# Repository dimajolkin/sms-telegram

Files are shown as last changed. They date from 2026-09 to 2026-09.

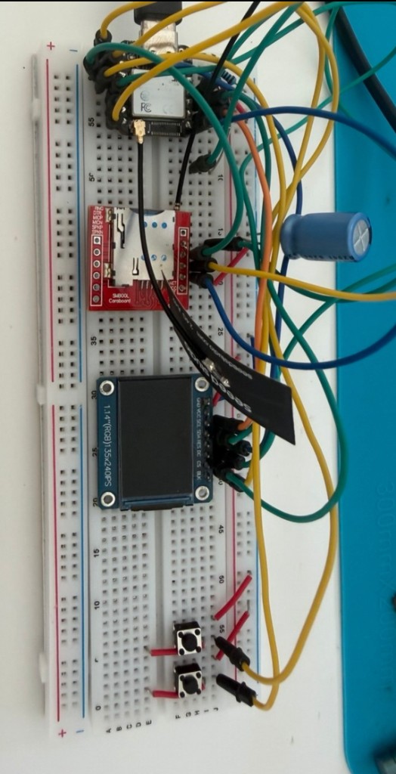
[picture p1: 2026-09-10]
docs/hardware/breadboard-prototype.jpg

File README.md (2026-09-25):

# SMS ↔ Telegram gateway (PlatformIO / Arduino)

Firmware for **Seeed XIAO ESP32-S3** that bridges a **SIM800L** cellular modem and **Telegram Bot API** over Wi‑Fi, with a Nokia-style **ST7789** status screen.

Uses **native ESP Wi‑Fi + mbedTLS** and **two FreeRTOS cores**. The device is a **gateway**: accept SMS / events and forward to Telegram — not a message store.

```text
  Phone / SMS ──► SIM800L ──UART──► XIAO ESP32-S3 ──Wi‑Fi TLS──► Telegram
                      ▲                    │
                      │                    └── ST7789 status UI
                 USSD / CLIP
```

| Core | Tasks |
|---|---|
| **0** (PRO) | Wi‑Fi stack, NTP, Telegram HTTPS / long-poll, outbound queue |
| **1** (APP) | SIM800L UART, SMS/CLIP poll, weekly balance check, ST7789 + buttons |

## Features

| Feature | Behavior |
|---|---|
| Incoming SMS | Queued → Telegram (UCS-2 decoded), then **deleted from SIM** |
| Missed calls | `AT+CLIP` → Telegram after ring silence |
| Outgoing SMS | `/sms +7900… text` |
| USSD / balance | `/balance` (`*100#`), `/ussd *code#` |
| Weekly balance | Every **7 days** (`*100#`); Telegram warning if balance **&lt; 100** |
| Missed list | `/missed` (modem MC/RC phonebook) |
| Status UI | Signal, Wi‑Fi, clock, **QUEUE** (pending TG sends), CALLS, **IP**, softkeys |
| Inbox | Browse SIM leftovers; **Next** = next / exit after last, **Back** = status |
| Buttons | D0 = Next / Inbox, D1 = OK / Refresh / Back (to GND) |

## Hardware

- [Seeed XIAO ESP32-S3](https://wiki.seeedstudio.com/xiao_esp32s3_getting_started/)
- SIM800L (or compatible) + SIM with SMS
- ST7789V 1.14″ IPS (135×240), rotation 180° in firmware
- Two momentary buttons to GND
- Bulk capacitor on modem VCC

Enclosure / STL / Fusion: [`hardware/enclosure/`](hardware/enclosure/). Photos: [`docs/hardware/`](docs/hardware/).

### Pinout (XIAO)

| Function | XIAO | GPIO |
|---|---|---|
| Modem RX ← MCU TX | **D6** | 43 |
| Modem TX → MCU RX | **D7** | 44 |
| Modem RST (idle HIGH) | **D2** | 3 |
| TFT SCL | D8 | 7 |
| TFT SDA (MOSI) | D10 | 9 |
| TFT CS | D9 | 8 |
| TFT DC | D4 | 5 |
| TFT RES | D5 | 6 |
| TFT BLK | D3 | 4 |
| Button Next | D0 → GND | 1 |
| Button OK | D1 → GND | 2 |

## Requirements

- [PlatformIO](https://platformio.org/) CLI (`pio`)
- Wi‑Fi credentials + Telegram bot token ([@BotFather](https://t.me/BotFather))

## Quick start

```bash
cp firmware/secrets.ini.example firmware/secrets.ini
# edit WIFI_SSID, WIFI_PASSWORD, TELEGRAM_BOT_TOKEN, TELEGRAM_CHAT_ID

make flash          # or: cd firmware && pio run -t upload
make monitor
```

Open the bot, send `/start` or `/help`. Incoming SMS and missed calls appear automatically. **QUEUE** on the screen is the Telegram outbound backlog (decrements after each successful send).

### Example commands

```text
/help
/balance
/missed
/sms +79001112233 hello
/ussd *100#
```

## Project layout

```text
firmware/            PlatformIO project (Arduino + FreeRTOS)
  platformio.ini
  secrets.ini.example
  include/           pins, config, events, headers
  src/               main, modem, telegram, ui, display, …
hardware/enclosure/  case STL / Fusion
```

## Notes

- Boot order: display → Wi‑Fi/NTP → UART/modem → Telegram → pinned tasks.
- Screen sleeps after 30 s idle; wake on button or SMS / missed call.
- Balance check timestamp is stored in NVS (`sms-gw` / `bal_chk`); first run ~2 min after boot, then every 7 days.

## License

Use and modify as you like for personal / educational projects.

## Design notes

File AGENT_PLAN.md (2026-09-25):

# AGENT_PLAN — SMS → Telegram (PlatformIO)

Notion: **SMS → Telegram** (Hobby).

## Архитектура

Seeed XIAO ESP32S3 + SIM800L + ST7789V 1.14.
PlatformIO Arduino + FreeRTOS: Core0 WiFi/Telegram, Core1 modem/UI.

## Команды бота

- `/start`, `/sms`, `/ussd`, `/balance`, `/missed`, `/help`

## UI (кнопки)

- Next (D0): Status→Inbox / следующий SMS
- OK (D1): refresh / Back на Status

## Очередь

1. `make flash` при подключённом USB
2. Проверить Status (QUEUE, IP) + Inbox Back
3. Реальный SMS / USSD

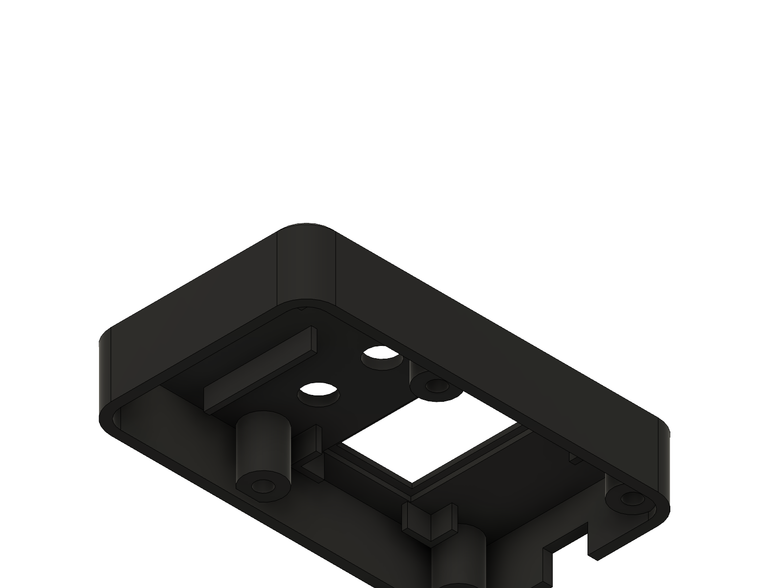
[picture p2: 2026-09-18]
docs/hardware/enclosure-shell-inside.png

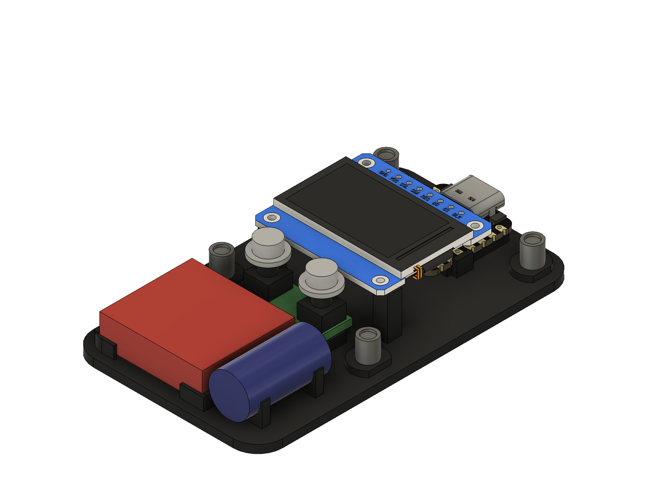
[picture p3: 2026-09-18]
docs/hardware/enclosure-packing.png

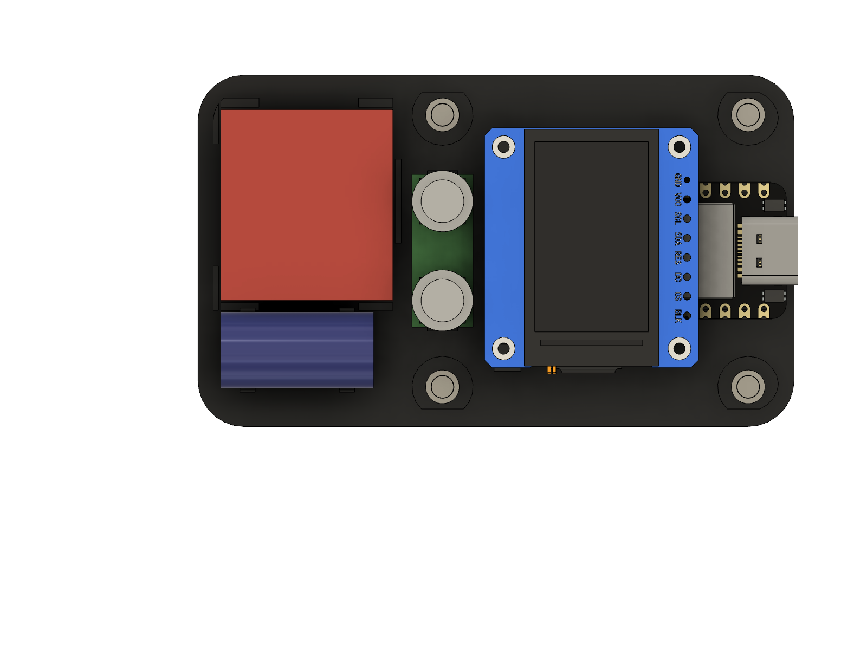
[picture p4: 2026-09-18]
docs/hardware/enclosure-packing-top.png

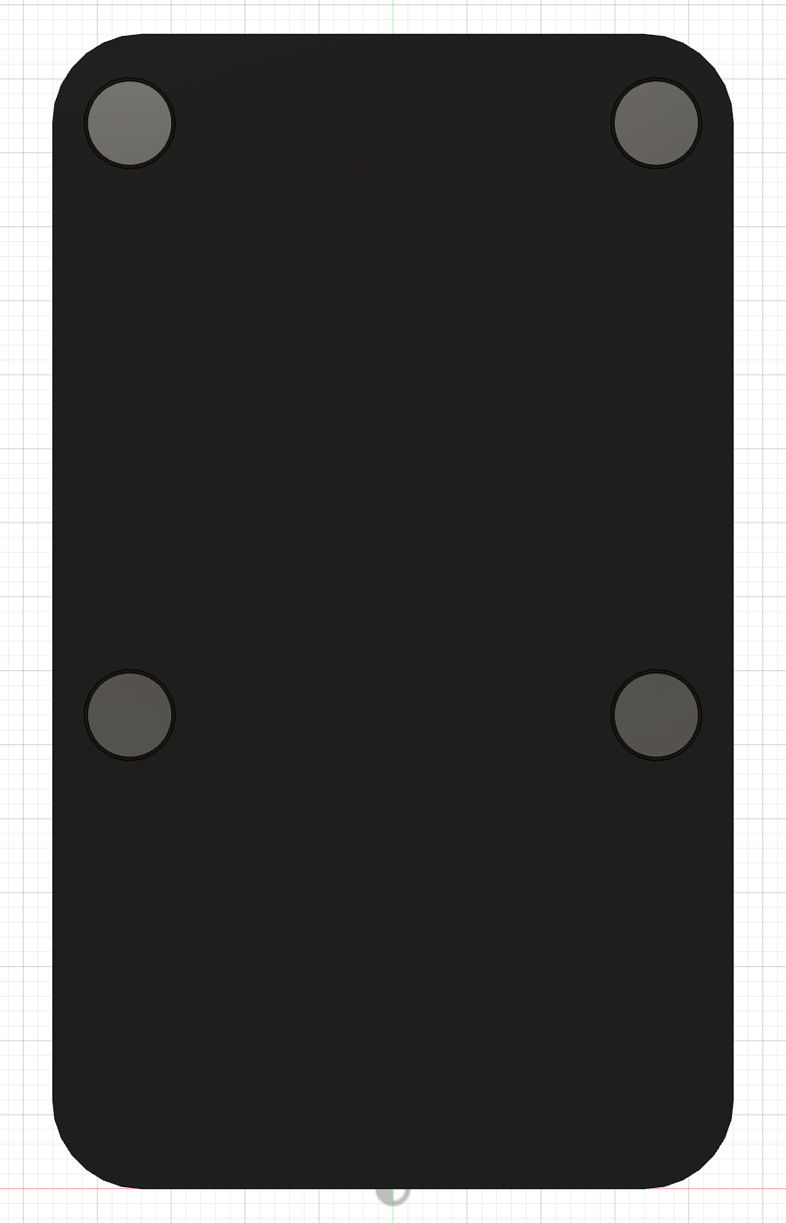
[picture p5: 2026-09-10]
docs/hardware/enclosure-bottom.png

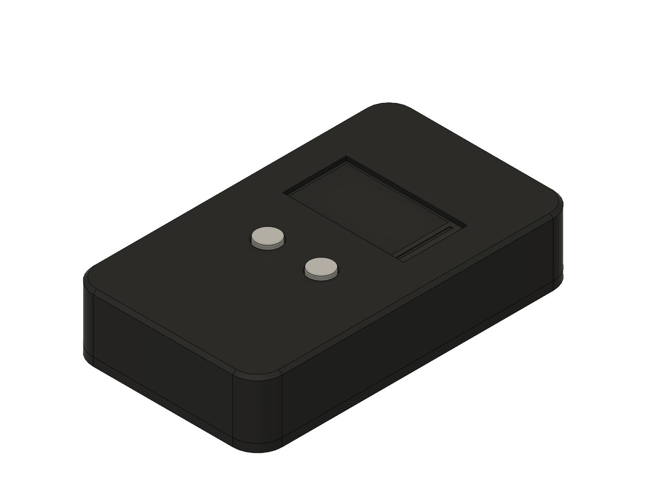
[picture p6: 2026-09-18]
docs/hardware/enclosure-iso.png

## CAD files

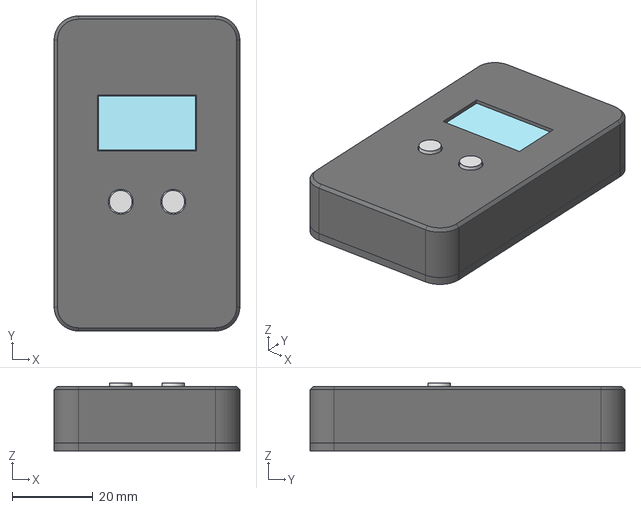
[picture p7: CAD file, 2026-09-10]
hardware/enclosure/sms-telegram-enclosure.step
46.0 x 78.0 x 16.8 mm

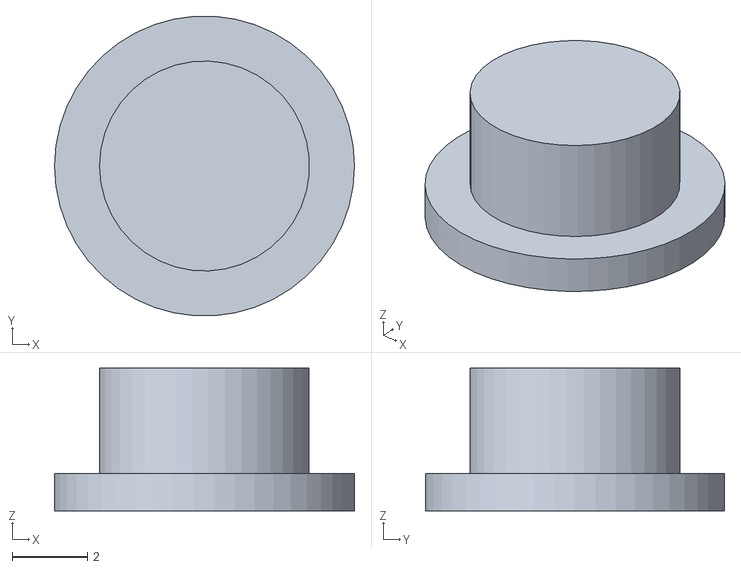
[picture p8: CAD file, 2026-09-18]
hardware/enclosure/stl/button-cap-x2.stl
8.00 x 7.98 x 3.80

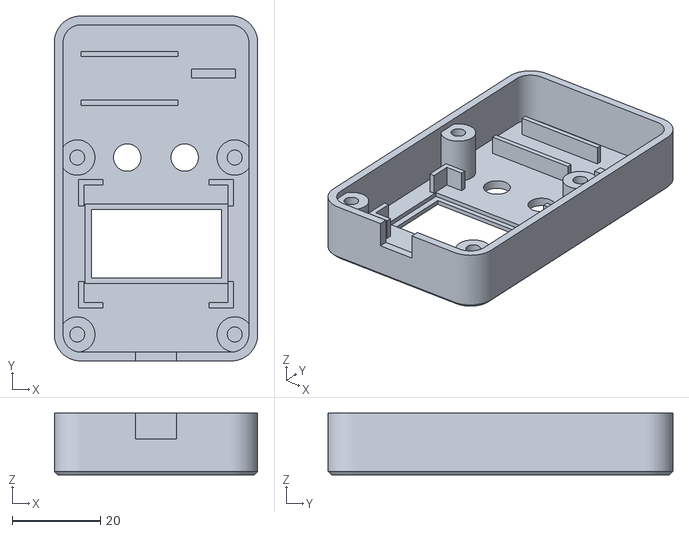
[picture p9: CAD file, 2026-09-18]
hardware/enclosure/stl/enclosure-shell.stl
46.0 x 78.0 x 14.0

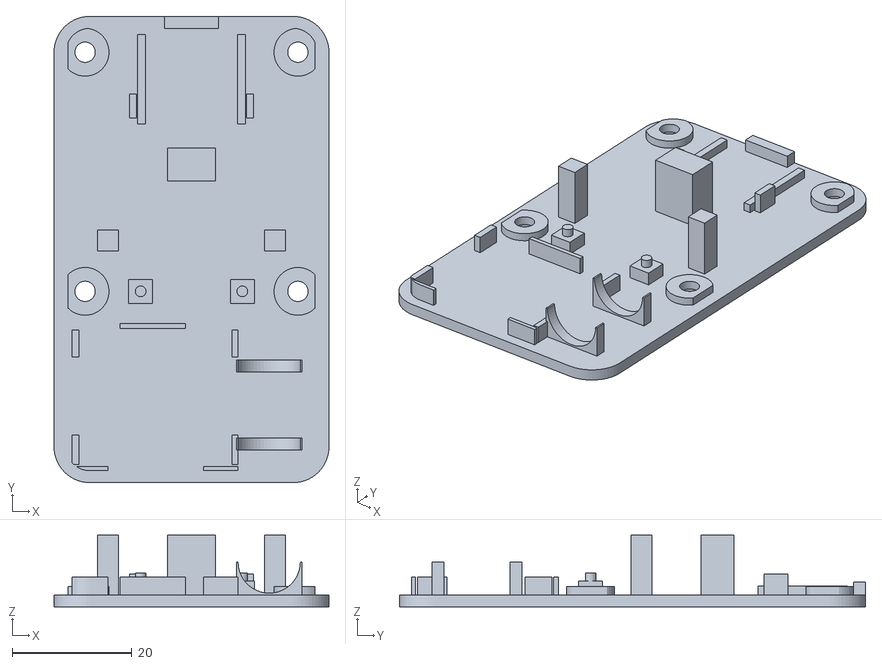
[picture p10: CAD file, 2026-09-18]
hardware/enclosure/stl/enclosure-cover.stl
46.0 x 78.0 x 12.0

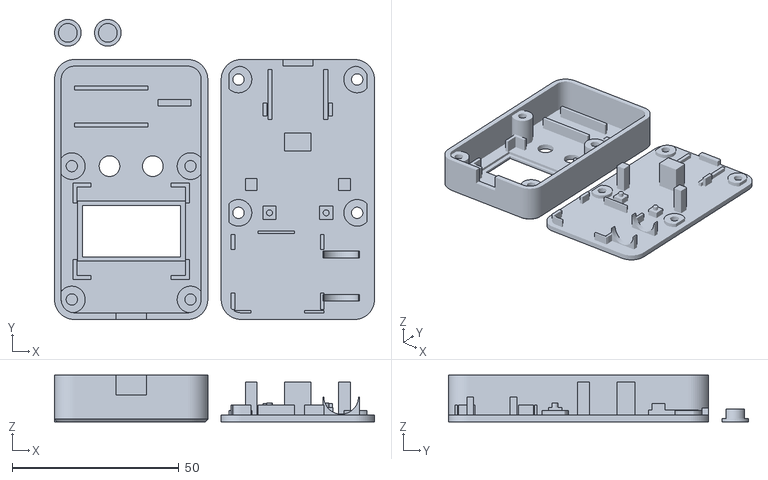
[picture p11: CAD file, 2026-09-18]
hardware/enclosure/stl/plate-100x160.stl
96.0 x 90.0 x 14.0

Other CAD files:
hardware/enclosure/sms-telegram-enclosure.f3d

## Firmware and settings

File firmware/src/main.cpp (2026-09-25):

#include <Arduino.h>
#include <HardwareSerial.h>
#include <Preferences.h>
#include <freertos/FreeRTOS.h>
#include <freertos/queue.h>
#include <freertos/semphr.h>
#include <freertos/task.h>
#include <ctype.h>
#include <stdlib.h>
#include <time.h>

#include "buttons.h"
#include "commands.h"
#include "config.h"
#include "display.h"
#include "events.h"
#include "modem.h"
#include "pins.h"
#include "status.h"
#include "telegram.h"
#include "ui.h"
#include "wifi_ntp.h"

static HardwareSerial ModemUART(1);
static SemaphoreHandle_t g_modem_mu;
static QueueHandle_t g_to_tg;
static QueueHandle_t g_to_modem;
static SharedStatus g_status;
static Modem g_modem;
static Telegram g_tg;
static Display g_disp;
static Buttons g_btns;
static UI g_ui;

static char g_chat_id[32];
static SemaphoreHandle_t g_chat_mu;

static void chat_set(const char *id) {
  if (xSemaphoreTake(g_chat_mu, pdMS_TO_TICKS(200)) != pdTRUE) return;
  strncpy(g_chat_id, id ? id : "", sizeof(g_chat_id) - 1);
  g_chat_id[sizeof(g_chat_id) - 1] = 0;
  xSemaphoreGive(g_chat_mu);
}

static void chat_get(char *out, size_t out_len) {
  out[0] = 0;
  if (xSemaphoreTake(g_chat_mu, pdMS_TO_TICKS(100)) != pdTRUE) return;
  strncpy(out, g_chat_id, out_len - 1);
  out[out_len - 1] = 0;
  xSemaphoreGive(g_chat_mu);
}

static void enqueue_tg(const TgEvent &ev) {
  if (xQueueSend(g_to_tg, &ev, pdMS_TO_TICKS(500)) == pdTRUE)
    status_tg_queue_add(&g_status, 1);
}

static void enqueue_text(const char *text) {
  TgEvent ev{};
  ev.type = TG_EVT_TEXT;
  ev.sms_index = -1;
  strncpy(ev.text, text, sizeof(ev.text) - 1);
  enqueue_tg(ev);
}

static bool tg_send_and_ack(const char *dest, const char *text) {
  bool ok = g_tg.send(dest, text);
  if (ok) status_tg_queue_add(&g_status, -1);
  return ok;
}

// Первое число вида 123 / 123.45 / 123,45 из ответа USSD.
static bool parseBalanceAmount(const char *text, float *out) {
  if (!text || !out) return false;
  for (const char *p = text; *p; p++) {
    if (!isdigit((unsigned char)*p)) continue;
    char buf[32];
    size_t n = 0;
    bool seen_sep = false;
    while (*p && n + 1 < sizeof(buf)) {
      if (isdigit((unsigned char)*p)) {
        buf[n++] = *p++;
      } else if ((*p == '.' || *p == ',') && !seen_sep) {
        seen_sep = true;
        buf[n++] = '.';
        p++;
      } else {
        break;
      }
    }
    buf[n] = 0;
    if (n == 0) continue;
    char *end = nullptr;
    float v = strtof(buf, &end);
    if (end != buf) {
      *out = v;
      return true;
    }
  }
  return false;
}

static void maybeCheckBalance() {
  time_t now = time(nullptr);
  if (now < 1700000000) return;  // NTP ещё нет

  static Preferences prefs;
  static bool prefs_open = false;
  if (!prefs_open) {
    prefs.begin("sms-gw", false);
    prefs_open = true;
  }

  time_t last = (time_t)prefs.getULong("bal_chk", 0);
  if (last == 0) {
    if (millis() < BALANCE_FIRST_CHECK_AFTER_MS) return;
  } else if (now - last < BALANCE_CHECK_INTERVAL_SEC) {
    return;
  }

  Serial.println("balance: weekly check *100#…");
  char resp[400];
  if (!g_modem.ussd("*100#", resp, sizeof(resp)) || !resp[0]) {
    Serial.println("balance: ussd fail, retry in 1d");
    // не ждать ещё 7 дней при ошибке
    prefs.putULong("bal_chk",
                   (uint32_t)(now - BALANCE_CHECK_INTERVAL_SEC + 86400));
    return;
  }
  prefs.putULong("bal_chk", (uint32_t)now);

  float bal = 0;
  if (!parseBalanceAmount(resp, &bal)) {
    Serial.printf("balance: parse fail [%s]\n", resp);
    return;
  }
  Serial.printf("balance: %.2f\n", bal);
  if (bal < BALANCE_WARN_BELOW) {
    char msg[220];
    snprintf(msg, sizeof(msg),
             "Низкий баланс: %.2f ₽ (порог %.0f).\n%s", bal,
             BALANCE_WARN_BELOW, resp);
    enqueue_text(msg);
  }
}

static void handle_update(const TgUpdate &u) {
  if (!u.has_message || u.text.length() == 0) return;
  String text = u.text;
  text.trim();
  char from[32];
  snprintf(from, sizeof(from), "%lld", (long long)u.chat_id);

  if (text.startsWith("/start")) {
    chat_set(from);
    enqueue_text("Подписка активна.\n/help");
    return;
  }

  char bound[32];
  chat_get(bound, sizeof(bound));
  if (bound[0] && strcmp(bound, from) != 0) {
    TgEvent ev{};
    ev.type = TG_EVT_TEXT;
    ev.sms_index = -1;
    strncpy(ev.from, from, sizeof(ev.from) - 1);
    strncpy(ev.text, "Этот бот привязан к другому chat id.", sizeof(ev.text) - 1);
    // send to requester: stash chat in from, special — use send with from
    // simpler: send directly
    g_tg.send(from, "Этот бот привязан к другому chat id.");
    return;
  }
  if (!bound[0]) chat_set(from);

  if (cmdMatch(text, "help")) {
    enqueue_text(helpText().c_str());
  } else if (cmdMatch(text, "balance")) {
    ModemCmd cmd{};
    cmd.type = MODEM_CMD_USSD;
    strncpy(cmd.arg1, "*100#", sizeof(cmd.arg1) - 1);
    xQueueSend(g_to_modem, &cmd, pdMS_TO_TICKS(500));
    enqueue_text("USSD *100#…");
  } else if (cmdMatch(text, "missed")) {
    ModemCmd cmd{};
    cmd.type = MODEM_CMD_LIST_MISSED;
    xQueueSend(g_to_modem, &cmd, pdMS_TO_TICKS(500));
    enqueue_text("Читаю пропущенные…");
  } else if (text.startsWith("/sms ")) {
    String num, body;
    if (!parseSMSCmd(text, &num, &body)) {
      enqueue_text("Формат: /sms +79001112233 текст");
      return;
    }
    ModemCmd cmd{};
    cmd.type = MODEM_CMD_SEND_SMS;
    strncpy(cmd.arg1, num.c_str(), sizeof(cmd.arg1) - 1);
    strncpy(cmd.arg2, body.c_str(), sizeof(cmd.arg2) - 1);
    xQueueSend(g_to_modem, &cmd, pdMS_TO_TICKS(500));
    enqueue_text("Отправляю SMS…");
  } else if (text.startsWith("/ussd ")) {
    String code = text.substring(6);
    code.trim();
    if (code.length() == 0) {
      enqueue_text("Формат: /ussd *100#");
      return;
    }
    ModemCmd cmd{};
    cmd.type = MODEM_CMD_USSD;
    strncpy(cmd.arg1, code.c_str(), sizeof(cmd.arg1) - 1);
    xQueueSend(g_to_modem, &cmd, pdMS_TO_TICKS(500));
    char msg[80];
    snprintf(msg, sizeof(msg), "USSD %s…", code.c_str());
    enqueue_text(msg);
  } else {
    enqueue_text("Не знаю команду. /help");
  }
}

static void telegram_task(void *arg) {
  (void)arg;
  Serial.printf("telegram_task on core %d\n", xPortGetCoreID());
  int64_t offset = 0;
  int fails = 0;
  uint32_t last_poll = 0;

  // drain backlog once
  {
    TgUpdate ups[3];
    int n = 0;
    int64_t next = 0;
    if (g_tg.getUpdates(0, 0, ups, &n, 3, &next)) {
      offset = next;
      for (int i = 0; i < n; i++) handle_update(ups[i]);
    }
  }

  char chat[32];
  chat_get(chat, sizeof(chat));
  if (chat[0]) g_tg.send(chat, "ESP online. /help");

  for (;;) {
    TgEvent ev;
    while (xQueueReceive(g_to_tg, &ev, 0) == pdTRUE) {
      chat_get(chat, sizeof(chat));
      if (!chat[0] && ev.type != TG_EVT_TEXT) {
        // нет подписчика — вернуть в очередь, не терять
        xQueueSend(g_to_tg, &ev, 0);
        break;
      }
      const char *dest = chat;
      bool ok = false;
      if (ev.type == TG_EVT_SMS) {
        char msg[520];
        snprintf(msg, sizeof(msg), "SMS from %s\n\n%s", ev.from, ev.text);
        ok = tg_send_and_ack(dest, msg);
        if (ok && ev.sms_index >= 0) {
          g_modem.deleteSMS(ev.sms_index);  // шлюз: не храним на SIM
        } else if (!ok) {
          xQueueSend(g_to_tg, &ev, 0);
          break;
        }
      } else if (ev.type == TG_EVT_MISSED) {
        char msg[96];
        snprintf(msg, sizeof(msg), "Пропущенный звонок\n\n%s", ev.from);
        ok = tg_send_and_ack(dest, msg);
        if (!ok) {
          xQueueSend(g_to_tg, &ev, 0);
          break;
        }
      } else {
        ok = tg_send_and_ack(dest, ev.text);
        if (!ok) {
          xQueueSend(g_to_tg, &ev, 0);
          break;
        }
      }
    }

    if (millis() - last_poll > TG_POLL_MS) {
      last_poll = millis();
      TgUpdate ups[2];
      int n = 0;
      int64_t next = offset;
      if (g_tg.getUpdates(offset, 1, ups, &n, 2, &next)) {
        fails = 0;
        status_set_wifi(&g_status, true);
        char ip[16];
        wifiLocalIP(ip, sizeof(ip));
        status_set_ip(&g_status, ip);
        offset = next;
        for (int i = 0; i < n; i++) handle_update(ups[i]);
      } else {
        fails++;
        status_set_wifi(&g_status, fails < 3);
        Serial.println("tg poll fail");
      }
    }
    vTaskDelay(pdMS_TO_TICKS(50));
  }
}

static void modem_task(void *arg) {
  (void)arg;
  Serial.printf("modem_task on core %d\n", xPortGetCoreID());
  uint32_t last_sms = 0;
  uint32_t last_bal_poll = 0;

  for (;;) {
    ModemCmd cmd;
    while (xQueueReceive(g_to_modem, &cmd, 0) == pdTRUE) {
      if (cmd.type == MODEM_CMD_SEND_SMS) {
        bool ok = g_modem.sendSMS(cmd.arg1, cmd.arg2);
        char msg[96];
        if (ok)
          snprintf(msg, sizeof(msg), "SMS отправлено на %s", cmd.arg1);
        else
          snprintf(msg, sizeof(msg), "Ошибка SMS");
        enqueue_text(msg);
      } else if (cmd.type == MODEM_CMD_USSD) {
        char resp[400];
        bool ok = g_modem.ussd(cmd.arg1, resp, sizeof(resp));
        if (!ok || !resp[0] || strcmp(resp, "OK") == 0)
          enqueue_text("USSD: пустой ответ или ошибка");
        else {
          char msg[480];
          snprintf(msg, sizeof(msg), "USSD\n%s", resp);
          enqueue_text(msg);
        }
      } else if (cmd.type == MODEM_CMD_LIST_MISSED) {
        MissedCall list[20];
        int n = g_modem.listMissedCalls(list, 20);
        int cnt = g_modem.missedCount();
        if (n < 0) {
          char msg[80];
          snprintf(msg, sizeof(msg), "Ошибка. Счётчик CALLS: %d", cnt);
          enqueue_text(msg);
        } else if (n == 0) {
          String msg = "Пропущенных в памяти модема нет.";
          if (cnt > 0) msg += "\nСчётчик CPBS=" + String(cnt);
          msg += "\nНовые звонки шлются сюда сами после гудков (CLIP).";
          enqueue_text(msg.c_str());
        } else {
          String b = "Пропущенные (" + String(n) + "):\n";
          for (int i = 0; i < n; i++) {
            b += String(list[i].index) + ". ";
            if (list[i].name[0]) {
              b += list[i].name;
              b += ' ';
            }
            b += list[i].number;
            b += '\n';
          }
          enqueue_text(b.c_str());
        }
      } else if (cmd.type == MODEM_CMD_REFRESH_STATUS) {
        int csq, bars;
        char op[24];
        g_modem.signalQuality(&csq, &bars);
        g_modem.operatorName(op, sizeof(op));
        status_update_modem(&g_status, bars, op, g_modem.smsCount(),
                            g_modem.missedCount());
      }
    }

    char num[32];
    if (g_modem.pollMissedCall(num, sizeof(num))) {
      Serial.printf("missed call: %s\n", num);
      TgEvent ev{};
      ev.type = TG_EVT_MISSED;
      ev.sms_index = -1;
      strncpy(ev.from, num, sizeof(ev.from) - 1);
      enqueue_tg(ev);
      g_ui.wake();
    }

    if (millis() - last_sms > SMS_POLL_MS) {
      last_sms = millis();
      SMS msgs[5];
      int n = g_modem.readUnreadSMS(msgs, 5);
      if (n > 0) {
        for (int i = 0; i < n; i++) {
          TgEvent ev{};
          ev.type = TG_EVT_SMS;
          ev.sms_index = msgs[i].index;
          strncpy(ev.from, msgs[i].from, sizeof(ev.from) - 1);
          strncpy(ev.text, msgs[i].text, sizeof(ev.text) - 1);
          enqueue_tg(ev);
          g_ui.wake();
        }
      }
    }

    if (millis() - last_bal_poll > BALANCE_POLL_MS) {
      last_bal_poll = millis();
      maybeCheckBalance();
    }

    vTaskDelay(pdMS_TO_TICKS(30));
  }
}

static void ui_task(void *arg) {
  (void)arg;
  Serial.printf("ui_task on core %d\n", xPortGetCoreID());
  for (;;) {
    g_ui.tick();
    if (g_btns.pending())
      vTaskDelay(pdMS_TO_TICKS(5));
    else
      vTaskDelay(pdMS_TO_TICKS(15));
  }
}

void setup() {
  Serial.begin(115200);
  delay(500);
  Serial.println("sms-telegram boot (PlatformIO/Arduino)");
  Serial.println("stages: 1=display  2=WiFi  3=UART+modem  4=Telegram+tasks");

  if (!WIFI_SSID[0] || !TELEGRAM_BOT_TOKEN[0]) {
    Serial.println("fatal: set WIFI_SSID / TELEGRAM_BOT_TOKEN in secrets.ini");
    for (;;) delay(2000);
  }

  g_modem_mu = xSemaphoreCreateMutex();
  g_chat_mu = xSemaphoreCreateMutex();
  g_to_tg = xQueueCreate(16, sizeof(TgEvent));
  g_to_modem = xQueueCreate(4, sizeof(ModemCmd));
  status_init(&g_status);
  chat_set(TELEGRAM_CHAT_ID);

  pinMode(PIN_MODEM_RST, OUTPUT);
  digitalWrite(PIN_MODEM_RST, HIGH);

  Serial.println("--- stage1 SPI ---");
  g_disp.begin();
  g_disp.drawBoot("wifi…");
  Serial.println("--- stage1 OK display ---");

  Serial.println("--- stage2 WiFi ---");
  while (!wifiConnect()) {
    g_disp.drawBoot("wifi retry…");
    delay(3000);
  }
  status_set_wifi(&g_status, true);
  {
    char ip[16];
    wifiLocalIP(ip, sizeof(ip));
    status_set_ip(&g_status, ip);
  }
  g_disp.drawBoot("ntp…");
  ntpSync();
  g_disp.drawBoot("modem…");
  Serial.println("--- stage2 OK wifi ---");

  Serial.println("--- stage3 UART ---");
  ModemUART.setRxBufferSize(1024);
  ModemUART.begin(UART_BAUD, SERIAL_8N1, PIN_UART_RX, PIN_UART_TX);
  g_modem.begin(&ModemUART, g_modem_mu);
  for (;;) {
    Serial.println("modem init…");
    if (g_modem.init()) break;
    Serial.println("modem init fail, retry");
    delay(2000);
  }
  g_disp.drawBoot("telegram…");
  Serial.println("--- stage3 OK modem ---");

  Serial.println("--- stage4 Telegram ---");
  g_tg.begin(TELEGRAM_BOT_TOKEN);
  if (g_tg.ping())
    Serial.println("tg ok");
  else
    Serial.println("tg ping fail");
  if (g_tg.setMyCommands())
    Serial.println("tg menu ok");
  else
    Serial.println("tg menu fail");

  g_btns.begin();
  g_ui.begin(&g_disp, &g_btns, &g_modem, &g_status);
  g_ui.refreshStatus();
  g_ui.tick();

  xTaskCreatePinnedToCore(telegram_task, "tg", 12288, nullptr, 1, nullptr, 0);
  xTaskCreatePinnedToCore(modem_task, "modem", 8192, nullptr, 1, nullptr, 1);
  xTaskCreatePinnedToCore(ui_task, "ui", 6144, nullptr, 2, nullptr, 1);

  Serial.println("--- stage4 OK ready ---");
}

void loop() { vTaskDelay(pdMS_TO_TICKS(1000)); }

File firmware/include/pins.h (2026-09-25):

#pragma once

// Seeed XIAO ESP32-S3 — D0…D10

static const int PIN_UART_TX = 43;  // D6 → Modem RX
static const int PIN_UART_RX = 44;  // D7 ← Modem TX

static const int PIN_TFT_SCK = 7;   // D8
static const int PIN_TFT_MOSI = 9;  // D10
static const int PIN_TFT_CS = 8;    // D9
static const int PIN_TFT_DC = 5;    // D4
static const int PIN_TFT_RST = 6;   // D5
static const int PIN_TFT_BL = 4;    // D3

static const int PIN_BTN_NEXT = 1;  // D0 → GND
static const int PIN_BTN_OK = 2;    // D1 → GND
static const int PIN_MODEM_RST = 3; // D2 → SIM800L RST

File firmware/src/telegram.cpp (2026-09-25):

#include "telegram.h"
#include "commands.h"
#include <ArduinoJson.h>
#include <HTTPClient.h>
#include <WiFiClientSecure.h>
#include <cctype>
#include <cstdio>
#include <cstring>

void Telegram::begin(const char *token) { token_ = token ? token : ""; }

String Telegram::apiURL(const char *method) const {
  return String("https://api.telegram.org/bot") + token_ + "/" + method;
}

bool Telegram::doRequest(const char *method, const char *url,
                         const char *payload, const char *content_type,
                         String *body_out, int *code_out, int max_body) {
  WiFiClientSecure client;
  client.setInsecure();
  HTTPClient https;
  https.setTimeout(45000);
  if (!https.begin(client, url)) {
    Serial.println("tg begin failed");
    return false;
  }
  https.setUserAgent("sms-telegram/2.0");
  int code;
  if (payload && content_type) {
    https.addHeader("Content-Type", content_type);
    code = https.POST((uint8_t *)payload, strlen(payload));
  } else if (strcmp(method, "POST") == 0) {
    code = https.POST("");
  } else {
    code = https.GET();
  }
  if (code_out) *code_out = code;
  String body = https.getString();
  if ((int)body.length() > max_body) body = body.substring(0, max_body);
  if (body_out) *body_out = body;
  https.end();
  return code > 0;
}

bool Telegram::send(const char *chat_id, const char *text) {
  if (!chat_id || !chat_id[0] || !text) return false;
  String url = apiURL("sendMessage");
  String form = "chat_id=" + String(chat_id) + "&text=";
  // URL-encode minimally
  for (const char *p = text; *p; p++) {
    char c = *p;
    if (c == ' ')
      form += '+';
    else if (isalnum((unsigned char)c) || c == '-' || c == '_' || c == '.' ||
             c == '~')
      form += c;
    else {
      char hex[8];
      snprintf(hex, sizeof(hex), "%%%02X", (unsigned char)c);
      form += hex;
    }
  }
  String body;
  int code = 0;
  if (!doRequest("POST", url.c_str(), form.c_str(),
                 "application/x-www-form-urlencoded", &body, &code, 512))
    return false;
  if (code >= 300) {
    Serial.printf("tg send http %d %s\n", code, body.c_str());
    return false;
  }
  return true;
}

bool Telegram::ping() {
  String url = apiURL("getMe");
  String body;
  int code = 0;
  if (!doRequest("GET", url.c_str(), nullptr, nullptr, &body, &code, 512))
    return false;
  if (code >= 300 || body.length() == 0 || body[0] != '{') {
    Serial.printf("tg getMe fail %d %s\n", code, body.c_str());
    return false;
  }
  Serial.printf("tg getMe: %s\n", body.substring(0, 80).c_str());
  return true;
}

bool Telegram::setMyCommands() {
  String payload = "{\"commands\":[";
  for (int i = 0; i < BOT_COMMANDS_N; i++) {
    if (i) payload += ',';
    payload += "{\"command\":\"";
    payload += BOT_COMMANDS[i].cmd;
    payload += "\",\"description\":\"";
    // escape quotes in desc
    for (const char *p = BOT_COMMANDS[i].desc; *p; p++) {
      if (*p == '"' || *p == '\\') payload += '\\';
      payload += *p;
    }
    payload += "\"}";
  }
  payload += "]}";
  String url = apiURL("setMyCommands");
  String body;
  int code = 0;
  if (!doRequest("POST", url.c_str(), payload.c_str(), "application/json",
                 &body, &code, 256))
    return false;
  return code < 300;
}

bool Telegram::getUpdates(int64_t offset, int timeout_sec, TgUpdate *out,
                          int *count, int max_n, int64_t *next_offset) {
  if (count) *count = 0;
  if (next_offset) *next_offset = offset;
  String url = apiURL("getUpdates");
  url += "?timeout=";
  url += timeout_sec;
  url += "&limit=";
  url += max_n > 0 ? max_n : 1;
  if (offset > 0) {
    url += "&offset=";
    url += String((long)offset);
  }
  String body;
  int code = 0;
  if (!doRequest("GET", url.c_str(), nullptr, nullptr, &body, &code, 4096))
    return false;
  if (code >= 300) return false;
  if (body.indexOf("\"result\":[]") >= 0) return true;

  JsonDocument doc;
  DeserializationError err = deserializeJson(doc, body);
  if (err) {
    Serial.printf("tg json: %s\n", err.c_str());
    return false;
  }
  if (!doc["ok"].as<bool>()) return false;
  JsonArray result = doc["result"].as<JsonArray>();
  int n = 0;
  int64_t next = offset;
  for (JsonObject u : result) {
    if (n >= max_n) break;
    out[n].update_id = u["update_id"] | 0;
    out[n].has_message = false;
    out[n].text = "";
    out[n].chat_id = 0;
    if (u["message"].is<JsonObject>()) {
      JsonObject m = u["message"];
      out[n].has_message = true;
      out[n].chat_id = m["chat"]["id"] | (int64_t)0;
      const char *t = m["text"] | "";
      out[n].text = t;
    }
    if (out[n].update_id >= next) next = out[n].update_id + 1;
    n++;
  }
  if (count) *count = n;
  if (next_offset) *next_offset = next;
  return true;
}

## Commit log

2026-09-10 feat: Nokia UI, missed-call notify, UCS2 SMS, and TinyGo cores patch
    Improve the gateway UX and modem events, document the project in English
    for TinyGo + Telegram, and vendor ESP32-S3 dual-core patch files.
2026-09-10 feat(hardware): 3D-printable enclosure with per-node fixtures and M3 fastening
    Two-part 46x78x16 mm body designed in Fusion 360: upper shell with landscape
    ST7789 window, flanged tact-switch caps, display pocket ribs, SIM800L and
    capacitor hold-downs, USB-C U-notch; bottom cover with rails, stops, saddles
    and four M3 heat-set bosses with recessed button heads. Adds STL/STEP/F3D
    exports, renders, breadboard photo and README assembly/printing notes.
    [button-cap-x2.stl, enclosure-cover.stl, enclosure-shell.stl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]
2026-09-10 chore(hardware): print-oriented STLs and a single 100x160 build plate
    Shell flipped face-down, all parts moved to z=0 at the origin, plus a
    combined plate file so the whole enclosure prints in one job.
    [button-cap-x2.stl, enclosure-cover.stl, enclosure-shell.stl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]
2026-09-10 fix(hardware): restore outward normals on the flipped shell STL
    [enclosure-shell.stl, plate-100x160.stl]
2026-09-18 feat(hardware): fit enclosure to vendor XIAO/display models
    Supports were sized against placeholder boxes, so the real boards did not
    sit on them: the XIAO rails ran outside its 17.8 mm textolite and the
    display rested on the wall next to the ESP instead of the posts.
    - rails moved under the XIAO PCB, display posts raised to the board plane
    - centre post extended to y 56 so it carries the display and doubles as
    the back stop for the XIAO when a USB cable is plugged in
    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
    [button-cap-x2.stl, enclosure-cover.stl, enclosure-shell.stl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]
2026-09-25 feat(firmware): rewrite on PlatformIO Arduino with dual-core FreeRTOS
    Native ESP Wi-Fi/TLS, Core0 Telegram queue, Core1 modem/UI; weekly balance
    warn, status QUEUE/IP; drop TinyGo/swtls/patches from main.
2026-10-11 feat(firmware): reassemble SMS PDUs and deliver them over a kept Telegram connection
    Long UCS-2 messages were split or forwarded as raw hex. Decode the full PDU, fetch unread SMS on /get-sms, and reuse the HTTPS socket so codes arrive inside the entry window.
